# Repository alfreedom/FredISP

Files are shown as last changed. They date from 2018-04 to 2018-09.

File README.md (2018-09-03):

# FredISP 

### AVR USB ISP programmer based on the FabISP project.

The FredISP is a tiny, low cost and opern source usb ISP programmer for AVR microcontrollers.

This project is based on the FabISP programmer and the V-USB usign USBtiny firmware and drivers.

The programmer is compatible with Windows, MacOS and Linux.

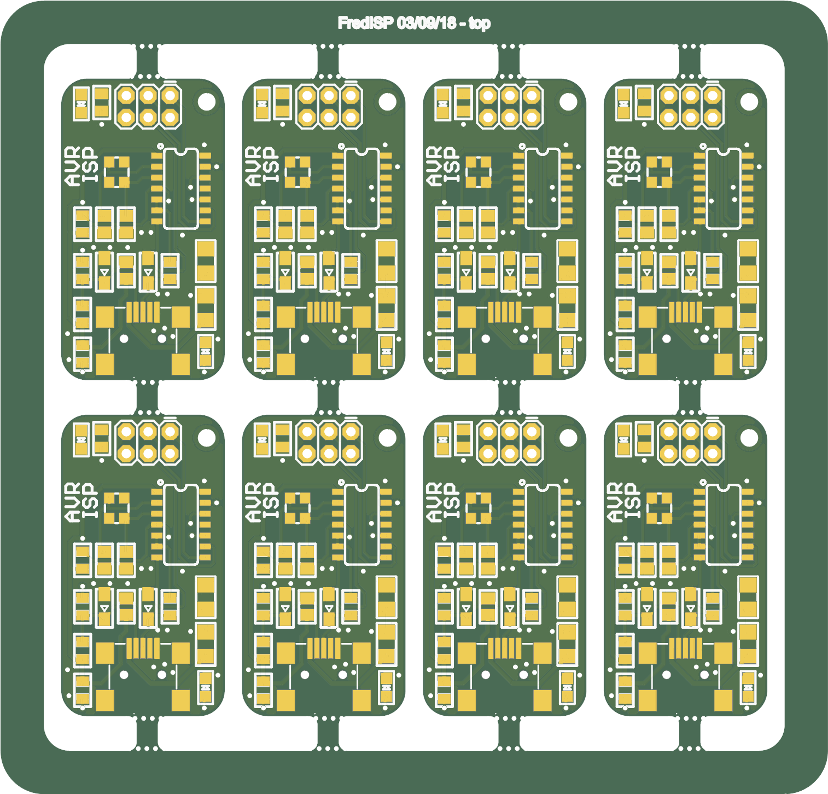
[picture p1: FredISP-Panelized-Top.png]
FredISP PCB

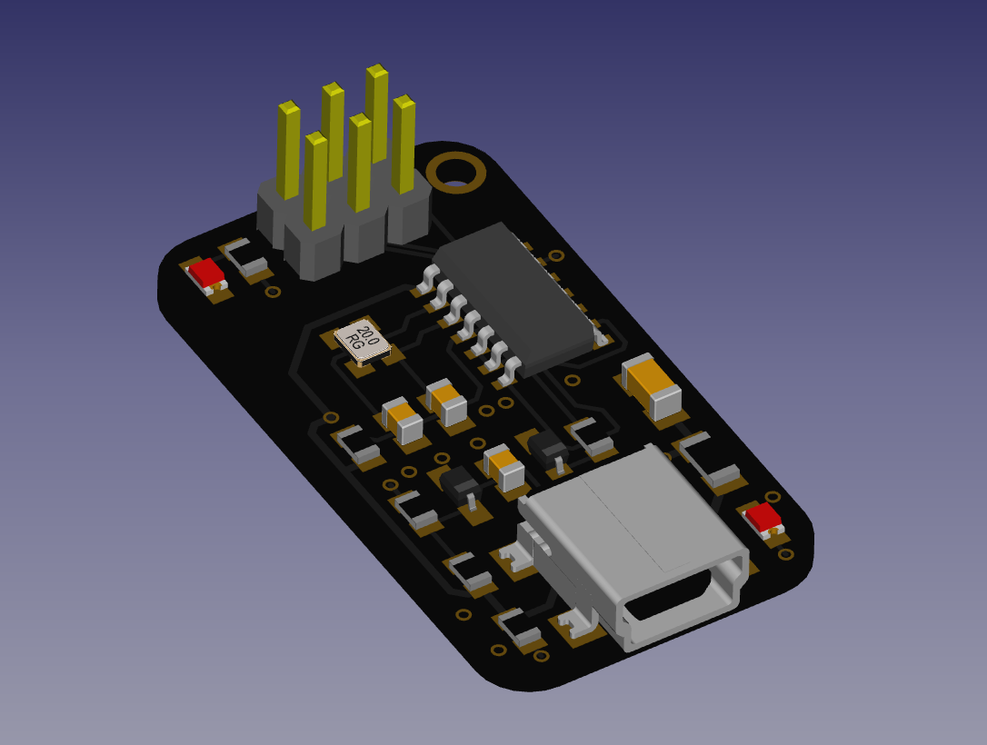
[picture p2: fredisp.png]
FredISP 3D Model


##### Project structure:

* Firmware folder: contains the firmware for the FredISP board. It was created with APOS tool and compiled for the ATtiny4 microcontroller running at 16 Mhz.
* Hardware folder: Contains the schematic and board Eagle files for the FredISP programmer.

----

### Installation

The programmer works with the usbtiny software, so the PC will recognize it as such. Linux and MacOS do not need to install drivers, the avrdude fotware is compatible with this programmer.

In Windows it is necessary to install the USBTiny driver of Adafruit® and the avrdude program. The driver installer is in the "drivers" folder. After having installed it, it will appear as "USBtiny" in the device manager.

To use the programmer it is necessary to install the avrdude software, which is available for Linux, MacOS and Windows systems.

In Linux operating systems it can be installed with the following commands:

Debian and derivates:

```bash
    sudo apt-get install avrdude
```

Fedora and RedHat:

```bash
    sudo yum install avrdude
```

Achr Linux and Derivates:

```bash
    sudo pacman -Sy avrdude
```

On MacOS operating systems it is possible to install it using homebrew:

```bash
    brew install avrdude
```

For Windows it is necessary to download the avrdude program executables and install them, preferably in the path C: \ windows \ avrdude. You must also add the installation folder to the end of the system path variablae.

[Download avrdude for windows](http://download.savannah.gnu.org/releases/avrdude/avrdude-6.3-mingw32.zip "avrdude download for Windows")

To use the FredISP with avrdude, you only need to specify the "usbtiny" programmer in the -c command line option, eg:

 avrdude __-c usbtiny__ -p atmega328p

---
### Linux users

In Linux it is necessary to make some configurations so that the avrdude program and the programmer are used without administrator's permission.

First you have to add your user to the "dialout" group (in debian based distributions) with the command:

``` bash
sudo adduser MYUSER dialout
``` 

Then you have to create the file with the device rules for avrdude in the path /etc/udev/rules.d (the path of the udev folder may vary from one system to another). It can be created with the following command:

``` bash
sudo touch /etc/udev/rules.d/99-avr.rules
``` 

You have to add the definitions of the programmers by editing the file:

``` bash
sudo nano /etc/udev/rules.d/99-avr.rules
``` 

``` bash
# Programmers for avrdude
ATTR{idVendor}=="03eb", ATTR{idProduct}=="2104", GROUP="dialout", MODE="0660" # AVRISP mkII
ATTR{idVendor}=="03eb", ATTR{idProduct}=="2107", GROUP="dialout", MODE="0660" # AVR-Dragon
ATTR{idVendor}=="03eb", ATTR{idProduct}=="2103", GROUP="dialout", MODE="0660" # JTAG ICE mkII
ATTR{idVendor}=="03eb", ATTR{idProduct}=="2106", GROUP="dialout", MODE="0660" # STK600
ATTR{idVendor}=="16c0", ATTR{idProduct}=="05dc", GROUP="dialout", MODE="0660" # USBASP von www.fischl.de
ATTR{idVendor}=="03eb", ATTR{idProduct}=="2ffa", GROUP="dialout", MODE="0660" # AT90USB
ATTR{idVendor}=="10c4", ATTR{idProduct}=="ea60", GROUP="dialout", MODE="0660" # AVR910
ATTR{idVendor}=="03eb", ATTR{idProduct}=="2105", GROUP="dialout", MODE="0660" # AVR ONE
ATTR{idVendor}=="03eb", ATTR{idProduct}=="210d", GROUP="dialout", MODE="0660" # Atmel XPLAIN CDC Gateway
ATTR{idVendor}=="03eb", ATTR{idProduct}=="2ffb", GROUP="dialout", MODE="0660" # AT90USB AVR DFU bootloader
ATTR{idVendor}=="1781", ATTR{idProduct}=="0c9f", GROUP="dialout", MODE="0660" # usbtiny
```
The group of udev rules depend of the Linux distribution, you need to check which group have the permissions to control the hardware, for example in Manjaro and Arch linux the group is __uucp__. 

And finally reload the device rules for the changes to take effect:

```bash
sudo udevadm control --reload 
sudo udevadm trigger --action=add
```

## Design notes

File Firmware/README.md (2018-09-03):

# FredISP Firmware

### Firmware for the USB ISP programmer FredISP

This folder contains the firmware for the FredISP v1.0 board. The projec was created whit APOS tool, and the code are based in the FabISP programmer and V-USB library.

To compile open the firmware folder in a terminal and type "make".
To install type "make install".

Note: you need to have installed the avr-gcc toolchain and the avrdude software.

The firmware run at 16 Mhz, but the frequency could be changed in the Makefile.

----

### Compile

1. Edit the DEVICE and CLOCK options in the makefile.
2. Enter the Firmware folder from the terminal and execute the "make" command.

There are compiled versions inside the "hex" folder for the attiny44 and attiny84 micros with frequencies of 12, 16 and 20 Mhz in case you do not want to compile the firmware. To install them just run the command:

```bash 
avrdude -c MYPROGRAMMER -p attiny44 -U flash:w:fredisp-1.0-t44-16Mhz.hex
```
---
### Install

1. Connect the FredISP hardware to another ISP programmer like USBASP, AVR-DRAGON, etc.
2. Edit the PROGRAMMER option in the makefile to configure your hardware ISP programmer.
3. Execute the command "make install" to download the firmware and program the fuses on the AVR microcontroller.

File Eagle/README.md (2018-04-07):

# FredISP Hardware

This folder contains the Eagle files for the FredISP board.

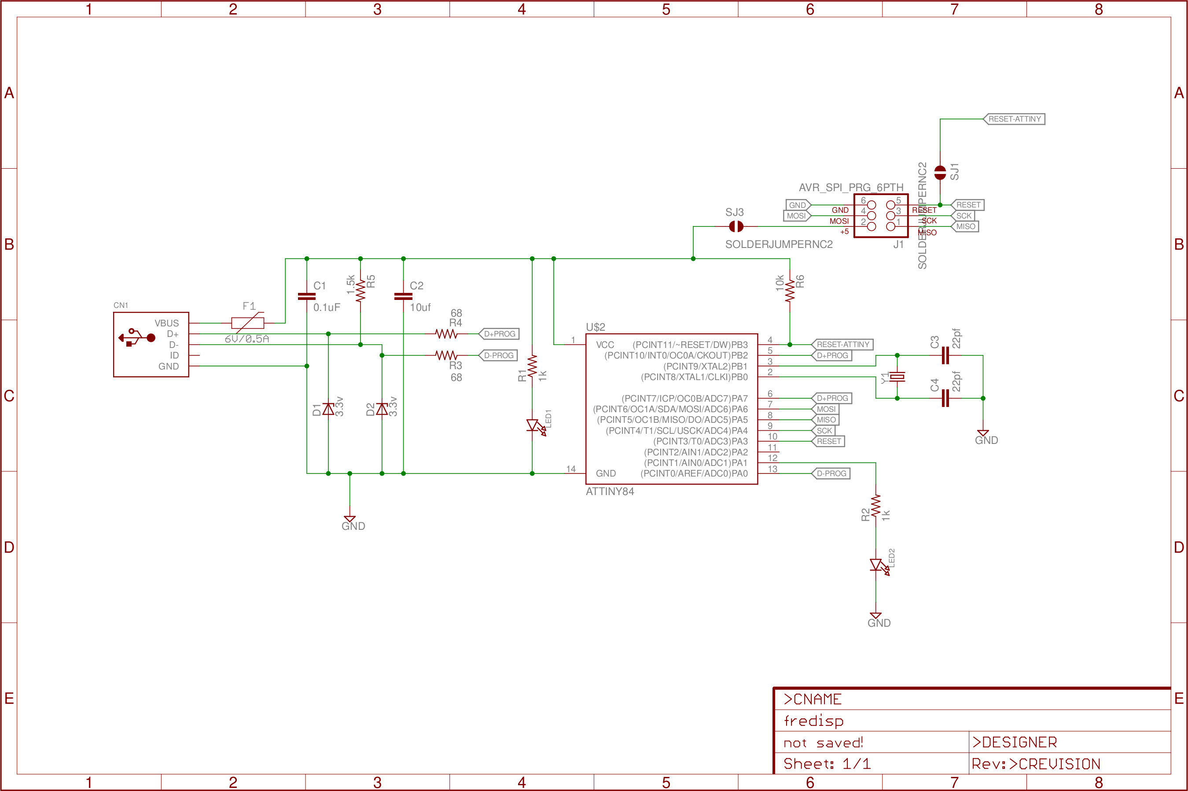
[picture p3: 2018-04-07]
schematic.jpg

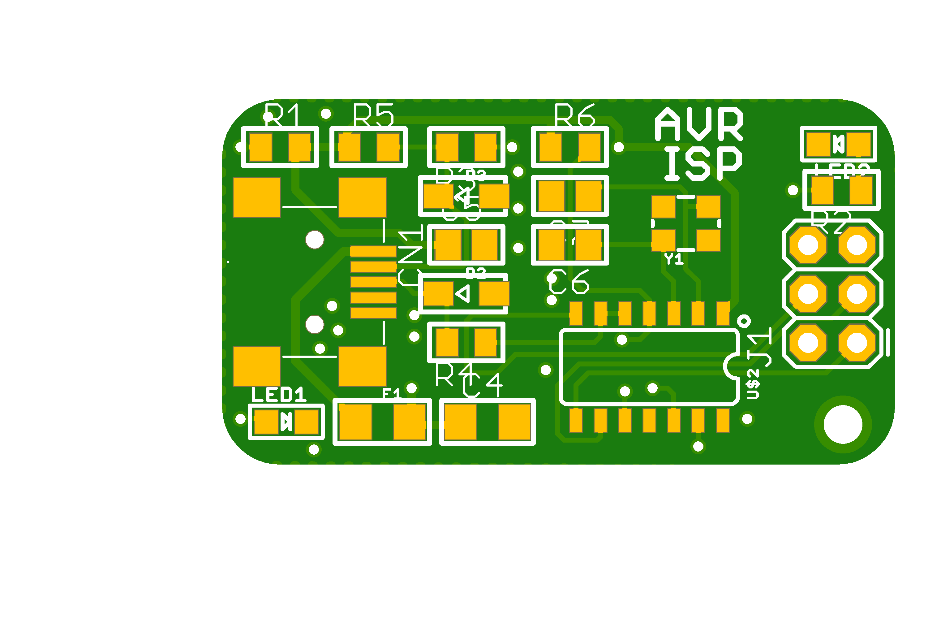
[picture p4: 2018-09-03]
FredISP-Top.png

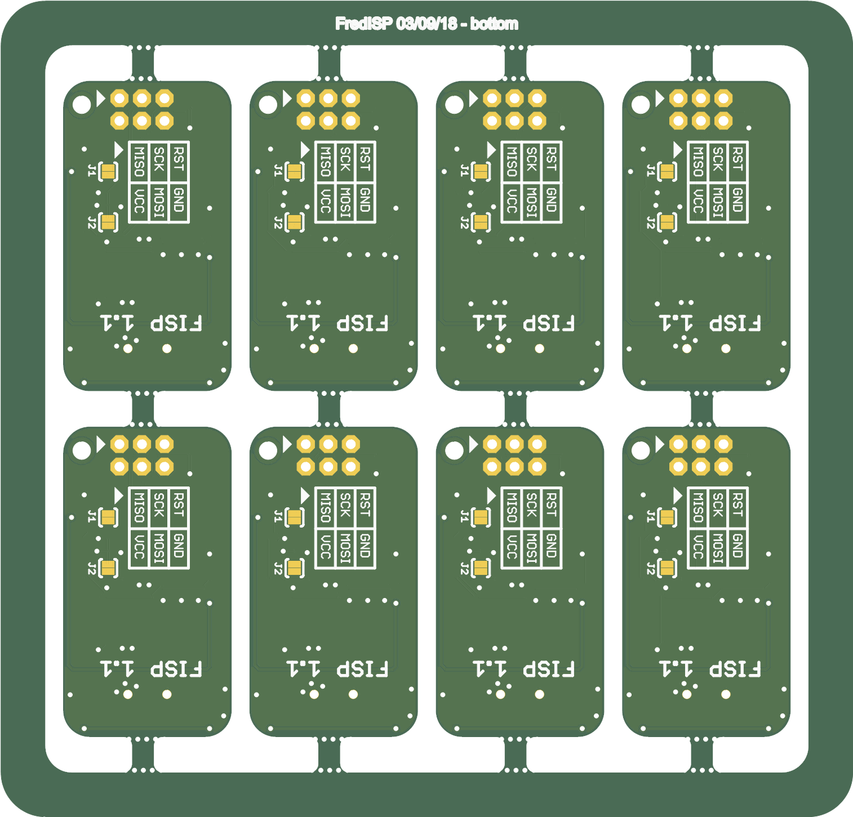
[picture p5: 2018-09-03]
FredISP-Panelized Bottom.png

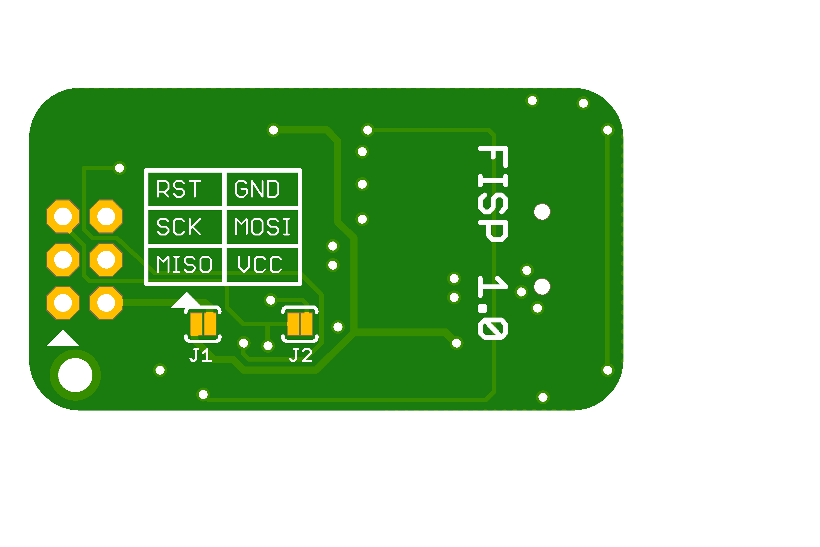
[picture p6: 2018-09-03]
FredISP-Bottom.png

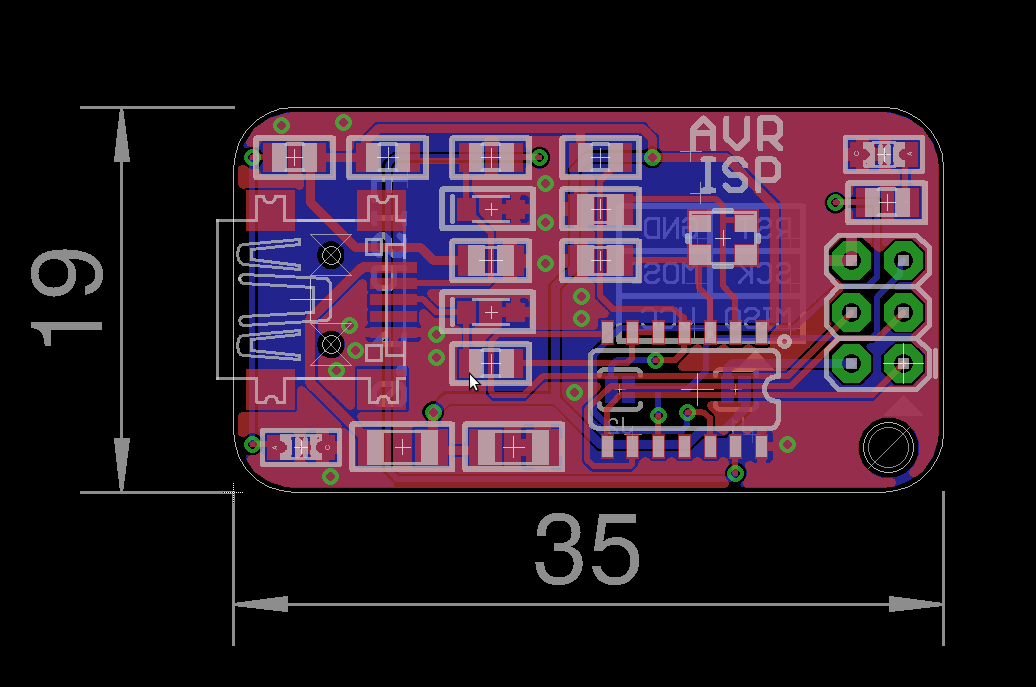
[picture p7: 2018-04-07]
FredISP-Size.png

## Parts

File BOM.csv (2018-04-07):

Part | Value | Device | Package | Description
C1 | 0.1uF | C-EUC0805 | C0805 | CAPACITOR
C2 | 10uf | C-EUC1206 | C1206 | CAPACITOR
C3 | 22pf | C-EUC0805 | C0805 | CAPACITOR
C4 | 22pf | C-EUC0805 | C0805 | CAPACITOR
CN1 |  | USBMINIB | USB-MINIB | USB Connectors
D1 | 3.3v | ZENER-DIODESOD80C | SOD80C | Z-Diode
D2 | 3.3v | ZENER-DIODESOD80C | SOD80C | Z-Diode
F1 | 6V/0.5A | PPTC_HALF-AMP | 1206 | Resettable Fuse PPTC
J1 | AVR_SPI_PRG_6PTH | AVR_SPI_PRG_6PTH | 2X3 | AVR ISP 6 Pin
LED1 |  | LED0805 | CHIPLED_0805 | LED
LED2 |  | LED0805 | CHIPLED_0805 | LED
R1 | 1k | R-US_R0805 | R0805 | RESISTOR
R2 | 1k | R-US_R0805 | R0805 | RESISTOR
R3 | 68 | R-US_R0805 | R0805 | RESISTOR
R4 | 68 | R-US_R0805 | R0805 | RESISTOR
R5 | 1.5k | R-US_R0805 | R0805 | RESISTOR
R6 | 10k | R-US_R0805 | R0805 | RESISTOR
SJ1 | SOLDERJUMPERNC2 | SOLDERJUMPERNC2 | SJ_2S-NOTRACE | Solder Jumper
SJ3 | SOLDERJUMPERNC2 | SOLDERJUMPERNC2 | SJ_2S-NOTRACE | Solder Jumper
U | ATTINY84 | ATTINY84 | SO14 | Atmel 14-pin 2/4/8kB flash uC
Y1 |  | CRYSTALSMD-3.2X2.5 | CRYSTAL-SMD-3.2X2.5MM | Crystals (Generic)

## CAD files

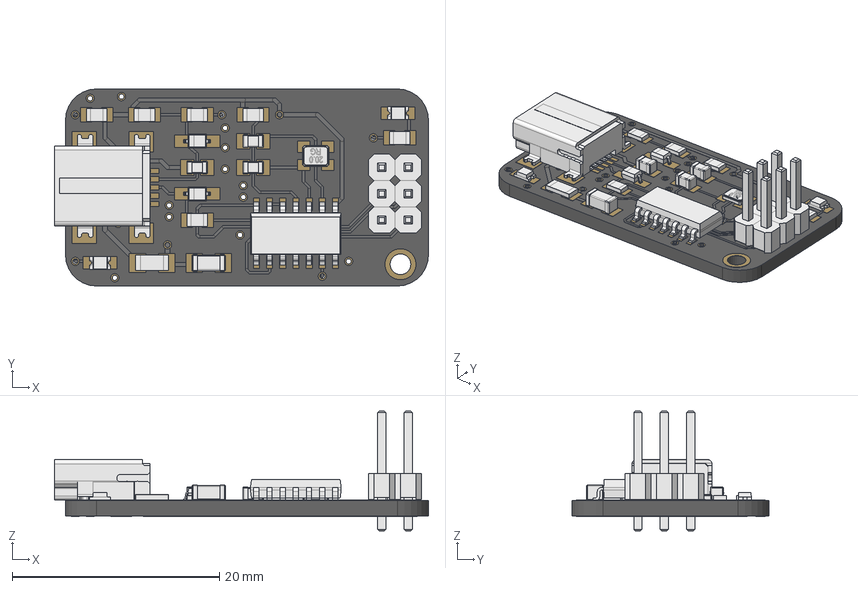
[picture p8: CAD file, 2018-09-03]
3D Model/fredisp 3d model freecad.FCStd
36.1 x 19.0 x 11.5 mm
Board
R1
R3
R4
R5
R6
F1
R2
LED1
LED2
J1
CN1
U$2
D2
D3
C4
C5
C6
C7
Y1
Top_1
Bottom_16
tPad_17
bPad_18

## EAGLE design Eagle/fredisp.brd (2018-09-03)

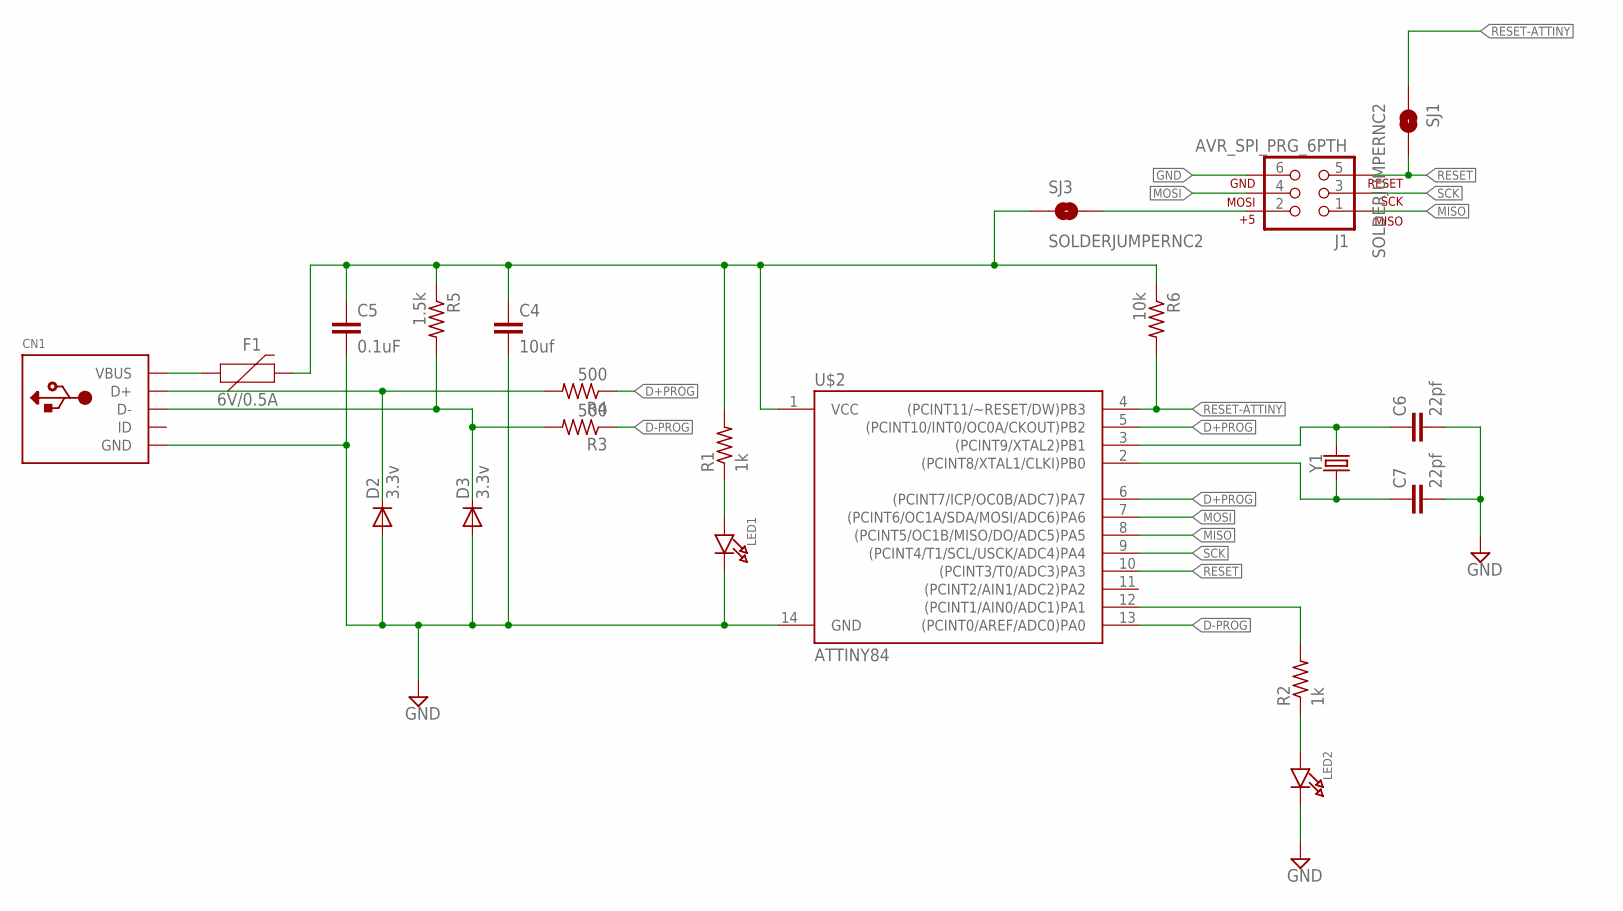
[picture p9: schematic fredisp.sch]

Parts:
C4: 10uf; C1206
C5: 0.1uF; C0805
C6, C7: 22pf; C0805
CN1: USBMINIB; USB-MINIB
D2, D3: 3.3v; SOD323-W
F1: 6V/0.5A; 1206
J1: AVR_SPI_PRG_6PTH; 2X3
LED1, LED2: LED0805; CHIPLED_0805
R1, R2: 1k; R0805
R3, R4: 500; R0805
R5: 1.5k; R0805
R6: 10k; R0805
SJ1, SJ3: SOLDERJUMPERNC2; SJ_2S-NOTRACE
U$2: ATTINY84; SO14
Y1: CRYSTALSMD-3.2X2.5; CRYSTAL-SMD-3.2X2.5MM

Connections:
D+PROG: R4.1, U$2.5 ((PCINT10/INT0/OC0A/CKOUT)PB2), U$2.6 ((PCINT7/ICP/OC0B/ADC7)PA7)
D-PROG: R3.1, U$2.13 ((PCINT0/AREF/ADC0)PA0)
GND: C4.2, C5.2, C6.2, C7.2, CN1.GND, D2.A, D3.A, J1.6, LED1.C, LED2.C, U$2.14 (GND)
MISO: J1.1, U$2.8 ((PCINT5/OC1B/MISO/DO/ADC5)PA5)
MOSI: J1.4, U$2.7 ((PCINT6/OC1A/SDA/MOSI/ADC6)PA6)
unnamed: C6.1, U$2.3 ((PCINT9/XTAL2)PB1), Y1.3 (2)
unnamed: CN1.D-, D3.C, R3.2, R5.2
unnamed: CN1.D+, D2.C, R4.2
unnamed: C7.1, U$2.2 ((PCINT8/XTAL1/CLKI)PB0), Y1.1
unnamed: J1.2, SJ3.2
unnamed: CN1.VBUS, F1.1
unnamed: LED1.A, R1.1
unnamed: LED2.A, R2.1
unnamed: R2.2, U$2.12 ((PCINT1/AIN0/ADC1)PA1)
RESET: J1.5, SJ1.2, U$2.10 ((PCINT3/T0/ADC3)PA3)
RESET-ATTINY: R6.2, SJ1.1, U$2.4 ((PCINT11/~RESET/DW)PB3)
SCK: J1.3, U$2.9 ((PCINT4/T1/SCL/USCK/ADC4)PA4)
VCC: C4.1, C5.1, F1.2, R1.2, R5.1, R6.1, SJ3.1, U$2.1 (VCC)

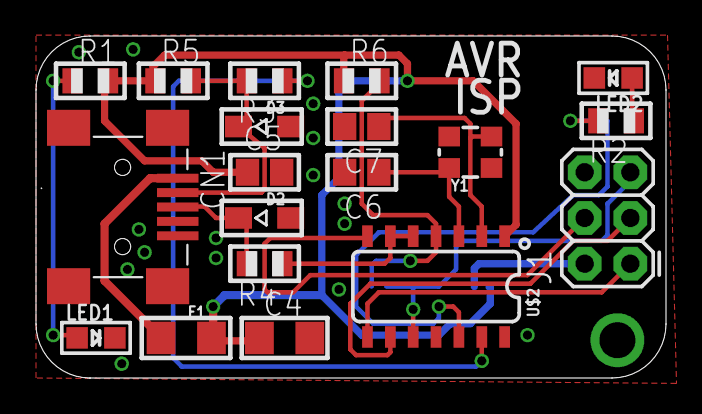
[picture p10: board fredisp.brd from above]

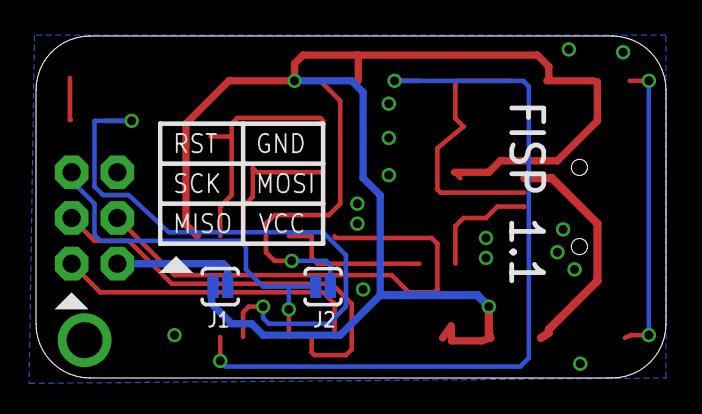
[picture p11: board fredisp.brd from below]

Board: 2 copper layers, 35.0 x 19.0 mm, 21 parts (2 on the bottom side), 18 nets.

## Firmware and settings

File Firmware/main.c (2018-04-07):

/******************************************************
 * main.c
 * 
 * Program Name:  FredISP
 *      Version:  1.0
 *         Date:  2018-01-07
 *       Author:  Alfredo Orozco
 *    Copyright:  ©2006-2008 Dick Streefland
 *    Copyright:  ©2008 by OBJECTIVE DEVELOPMENT Software GmbH
 *    Copyright:  ©2018 Alfredo Orozco
 *      License:  GNU GPL v2 (see License.txt), GNU GPL v3
 *
 * Description:
 *  AVR ISP USB programmer using V-USB
 * 	Based on the project FabISP and the work of 
 *  Dick Streefland and Christian Starkjohann
 * 
 *****************************************************/
#include <avr/io.h> 
#include <util/delay.h>
#include <avr/wdt.h>
#include <avr/interrupt.h>
#include <avr/pgmspace.h>
#include "usbdrv.h"

typedef uint8_t byte;
typedef uint16_t word;
// Comandos para el programador USBtiny
typedef enum{
	// Comandos generales
	USBTINY_REQUEST_ECHO          = 0x00,   // 0x00: echo test
	USBTINY_REQUEST_READ          = 0x01,   // 0x01: read byte (wIndex:address)
	USBTINY_REQUEST_WRITE         = 0x02,   // 0x02: write byte (wIndex:address, wValue:value)
	USBTINY_REQUEST_CLR           = 0x03,   // 0x03: clear bit (wIndex:address, wValue:bitno)
	USBTINY_REQUEST_SET           = 0x04,   // 0x04: set bit (wIndex:address, wValue:bitno)
	// Comandos de programación
	USBTINY_REQUEST_POWERUP       = 0x05,   // 0x05: apply power (wValue:SCK-period, wIndex:RESET)
	USBTINY_REQUEST_POWERDOWN     = 0x06,   // 0x06: remove power from chip
	USBTINY_REQUEST_SPI           = 0x07,   // 0x07: issue SPI command (wValue:c1c0, wIndex:c3c2)
	USBTINY_REQUEST_POLL_BYTES    = 0x08,   // 0x08: set poll bytes for write (wValue:p1p2)
	USBTINY_REQUEST_FLASH_READ    = 0x09,   // 0x09: read flash (wIndex:address)
	USBTINY_REQUEST_FLASH_WRITE   = 0x0A,   // 0x0A: write flash (wIndex:address, wValue:timeout)
	USBTINY_REQUEST_EEPROM_READ   = 0x0B,   // 0x0B: read eeprom (wIndex:address)
	USBTINY_REQUEST_EEPROM_WRITE  = 0x0C,   // 0x0C: write eeprom (wIndex:address, wValue:timeout)
}ustiny_cmd_t;

// Define los puertos y los pines del micro para SPI
#define SPI_DDR DDRA
#define SPI_PORT PORTA
#define SPI_PIN PINA
#define SPI_MOSI 6
#define SPI_MISO 5
#define SPI_SCK 4
#define RESET_PIN 3
#define POWER_PIN 1
#define STATUS_LED 1

#define SPI_MASK ((1 << SPI_MOSI) | (1 << SPI_SCK) | (1 << POWER_PIN) | (1 << RESET_PIN) | (0 << SPI_MISO) | (1 << STATUS_LED))
#define SPI_INIT SPI_DDR |= SPI_MASK
#define SPI_DEINIT SPI_DDR &= ~SPI_MASK
// Macros para escribir en pines de salida (1 y 0)
#define SPI_MOSI_HIGH (SPI_PORT |= (1 << SPI_MOSI))
#define SPI_MOSI_LOW (SPI_PORT &= ~(1 << SPI_MOSI))

#define SPI_SCK_HIGH (SPI_PORT |= (1 << SPI_SCK))
#define SPI_SCK_LOW (SPI_PORT &= ~(1 << SPI_SCK))

#define RESET_PIN_HIGH SPI_PORT |= (1 << RESET_PIN)

#define STATUS_LED_OFF SPI_PORT &= ~(1 << STATUS_LED)
#define STATUS_LED_ON SPI_PORT |= (1 << STATUS_LED)

// Macro para leer pin de entrada MISO
#define SPI_MISO_STATE (SPI_PIN & (1 << SPI_MISO))

static byte sck_period;  // Periodo del reloj SPI (SCK)
static byte poll1;       // Primer byte de poleo para escritura
static byte poll2;       // Segundo byte de poleo para escritura
static word address;     // Dirección para lectura o escritura
static word timeout;     // Timeout de espera para escritura
static byte curremt_cmd; // Comando actual de lectura o escritura
static byte cmd[4];      // Buffer de comandos
static byte res[4];      // Buffer de resultados de comandos
static byte buffer[8];   // Buffer para intercambio de datos USB

/*
 * Hace un retardo de 0.5 microsegundos las veces indicadas por
 * la variable sck_period  (0.5 us * skc_period)
 */
__attribute__((always_inline)) static void delay()
{
	asm volatile(
		"	mov	__tmp_reg__,%0	\n"
		"0:	rjmp	1f		\n"
		"1:	nop			\n"
		"	dec	__tmp_reg__	\n"
		"	brne	0b		\n"
		:
		: "r"(sck_period));
}

/*
 * Envía un commando ISP al dispositivo.
 */
static void spi_send_command(uint8_t *command, uint8_t *response)
{
	byte i, j, resp;

	for (i = 0; i < 4; i++)
	{
	STATUS_LED_ON;
		resp = 0;
		for (j = 0; j < 8; j++)
		{
			if ((command[i] << j) & 0x80)
				SPI_MOSI_HIGH;

			delay();
			SPI_SCK_HIGH;
			delay();

			resp <<= 1;
			if (SPI_MISO_STATE)
				resp |= 1;

			SPI_SCK_LOW;
			SPI_MOSI_LOW;
		}
		response[i] = resp;
	STATUS_LED_OFF;
	}
}

/*
 * Crea un comando de lectura o escritura y lo envía al dispositivo.
 */
static void spi_request_rw()
{
	word aux;

	aux = address++;
	if (curremt_cmd & 0x80)
		aux <<= 1;

	cmd[0] = curremt_cmd;
	if (aux & 1)
		cmd[0] |= 0x08;

	cmd[1] = aux >> 9;
	cmd[2] = aux >> 1;

	spi_send_command(cmd, res);
}

/**
 * Función para manejar un paquete SETUP no estandar
 */
extern usbMsgLen_t usbFunctionSetup(byte data[8])
{
	byte i, mask, req;
	byte *addr;

	req = data[1];
	if (req == USBTINY_REQUEST_ECHO)
	{
		for (i = 0; i < 8; i++)
			buffer[i] = data[i];

		usbMsgPtr = buffer;
		return 8;
	}

	addr = (byte *)(int)data[4];
	if (req == USBTINY_REQUEST_READ)
	{
		buffer[0] = *addr;
		usbMsgPtr = buffer;
		return 1;
	}

	if (req == USBTINY_REQUEST_WRITE)
	{
		*addr = data[2];
		return 0;
	}
	mask = 1 << (data[2] & 7);

	if (req == USBTINY_REQUEST_CLR)
	{
		*addr &= ~mask;
		return 0;
	}

	if (req == USBTINY_REQUEST_SET)
	{
		*addr |= mask;
		return 0;
	}

	if (req == USBTINY_REQUEST_POWERUP)
	{
		sck_period = data[2];
		SPI_INIT;
		if (data[4])
			SPI_PORT = (SPI_PORT & ~SPI_MASK) | (1 << POWER_PIN) | (1 << RESET_PIN);
		else
			SPI_PORT = (SPI_PORT & ~SPI_MASK) | (1 << POWER_PIN);

		return 0;
	}

	if (req == USBTINY_REQUEST_POWERDOWN)
	{
		RESET_PIN_HIGH;
		SPI_PORT &= ~SPI_MASK;
		SPI_DEINIT;

		return 0;
	}

	if (!(SPI_DDR & 0x7E))
		return 0;

	if (req == USBTINY_REQUEST_SPI)
	{
		spi_send_command(data + 2, buffer);
		usbMsgPtr = buffer;
		return 4;
	}

	if (req == USBTINY_REQUEST_POLL_BYTES)
	{
		poll1 = data[2];
		poll2 = data[3];
		return 0;
	}

	address = *(word *)&data[4];
	if (req == USBTINY_REQUEST_FLASH_READ)
	{
		curremt_cmd = 0x20;
		return USB_NO_MSG;
	}

	if (req == USBTINY_REQUEST_EEPROM_READ)
	{
		curremt_cmd = 0xa0;
		return USB_NO_MSG;
	}
	timeout = *(word *)&data[2];

	if (req == USBTINY_REQUEST_FLASH_WRITE)
	{
		curremt_cmd = 0x40;
		return USB_NO_MSG;
	}

	if (req == USBTINY_REQUEST_EEPROM_WRITE)
	{
		curremt_cmd = 0xc0;
		return USB_NO_MSG;
	}
	return 0;
}

/*
 * Procesa un paquete de entrada (IN)
 * Lee información del dispositivo por SPI y son enviados 
 * por USB.
 */
extern byte usbFunctionRead(byte *data, byte len)
{
	byte i;

	for (i = 0; i < len; i++)
	{
		spi_request_rw();
		data[i] = res[3];
	}
	return len;
}

/*
 * Procesa un paquete de salida (OUT)
 * Lee los datos recibidos por USB y envía
 * los comandos por SPI
 */
extern byte usbFunctionWrite(byte *data, byte len)
{
	byte i, resp;
	word time;

	for (i = 0; i < len; i++)
	{
		cmd[3] = data[i];
		spi_request_rw();
		cmd[0] ^= 0x60; // turn write into read
		for (time = 0; time < timeout; time += 32 * sck_period)
		{ // when timeout > 0, poll until byte is written
			spi_send_command(cmd, res);
			resp = res[3];
			if (resp == cmd[3] && resp != poll1 && resp != poll2)
				break;
		}
	}

	return 1;
}

int main()
{
	byte i;

	usbInit();
	usbDeviceDisconnect();
	i = 0;
	while (--i)
	{
		wdt_reset();
		_delay_ms(1);
	}
	usbDeviceConnect();
	sei();
	while (1)
	{
		wdt_reset();
		usbPoll();
	}
	return 0;
}

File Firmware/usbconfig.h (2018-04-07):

/* Name: usbconfig.h
 * Project: V-USB, virtual USB port for Atmel's(r) AVR(r) microcontrollers
 * Author: Christian Starkjohann
 * Creation Date: 2005-04-01
 * Tabsize: 4
 * Copyright: (c) 2005 by OBJECTIVE DEVELOPMENT Software GmbH
 * License: GNU GPL v2 (see License.txt), GNU GPL v3 or proprietary (CommercialLicense.txt)
 * This Revision: $Id: usbconfig-prototype.h 767 2009-08-22 11:39:22Z cs $
 */

#ifndef __usbconfig_h_included__
#define __usbconfig_h_included__

/*
General Description:
This file is an example configuration (with inline documentation) for the USB
driver. It configures V-USB for USB D+ connected to Port D bit 2 (which is
also hardware interrupt 0 on many devices) and USB D- to Port D bit 4. You may
wire the lines to any other port, as long as D+ is also wired to INT0 (or any
other hardware interrupt, as long as it is the highest level interrupt, see
section at the end of this file).
*/

/* ---------------------------- Hardware Config ---------------------------- */

#define USB_CFG_IOPORTNAME      A
/* This is the port where the USB bus is connected. When you configure it to
 * "B", the registers PORTB, PINB and DDRB will be used.
 */
#define USB_CFG_DMINUS_BIT      0
/* This is the bit number in USB_CFG_IOPORT where the USB D- line is connected.
 * This may be any bit in the port.
 */
#define USB_CFG_DPLUS_BIT       7
/* This is the bit number in USB_CFG_IOPORT where the USB D+ line is connected.
 * This may be any bit in the port. Please note that D+ must also be connected
 * to interrupt pin INT0! [You can also use other interrupts, see section
 * "Optional MCU Description" below, or you can connect D- to the interrupt, as
 * it is required if you use the USB_COUNT_SOF feature. If you use D- for the
 * interrupt, the USB interrupt will also be triggered at Start-Of-Frame
 * markers every millisecond.]
 */
#define USB_CFG_CLOCK_KHZ       (F_CPU/1000)
/* Clock rate of the AVR in kHz. Legal values are 12000, 12800, 15000, 16000,
 * 16500 and 20000. The 12.8 MHz and 16.5 MHz versions of the code require no
 * crystal, they tolerate +/- 1% deviation from the nominal frequency. All
 * other rates require a precision of 2000 ppm and thus a crystal!
 * Default if not specified: 12 MHz
 */
#define USB_CFG_CHECK_CRC       0
/* Define this to 1 if you want that the driver checks integrity of incoming
 * data packets (CRC checks). CRC checks cost quite a bit of code size and are
 * currently only available for 18 MHz crystal clock. You must choose
 * USB_CFG_CLOCK_KHZ = 18000 if you enable this option.
 */

/* ----------------------- Optional Hardware Config ------------------------ */

/* #define USB_CFG_PULLUP_IOPORTNAME   D */
/* If you connect the 1.5k pullup resistor from D- to a port pin instead of
 * V+, you can connect and disconnect the device from firmware by calling
 * the macros usbDeviceConnect() and usbDeviceDisconnect() (see usbdrv.h).
 * This constant defines the port on which the pullup resistor is connected.
 */
/* #define USB_CFG_PULLUP_BIT          4 */
/* This constant defines the bit number in USB_CFG_PULLUP_IOPORT (defined
 * above) where the 1.5k pullup resistor is connected. See description
 * above for details.
 */

/* --------------------------- Functional Range ---------------------------- */
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

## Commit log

2018-04-07 Add FredISP v1.0
    [BOM.csv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]
2018-09-03 FredISP v1.1
    - Update the SMD Zener diode footprint
    - Update Panelized Gerbers with frame
    - Add 3D model in STEP and Freecad format.
    [BOM.csv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]

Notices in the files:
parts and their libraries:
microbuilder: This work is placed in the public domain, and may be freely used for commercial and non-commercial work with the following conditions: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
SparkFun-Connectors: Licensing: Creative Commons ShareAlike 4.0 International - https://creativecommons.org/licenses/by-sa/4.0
